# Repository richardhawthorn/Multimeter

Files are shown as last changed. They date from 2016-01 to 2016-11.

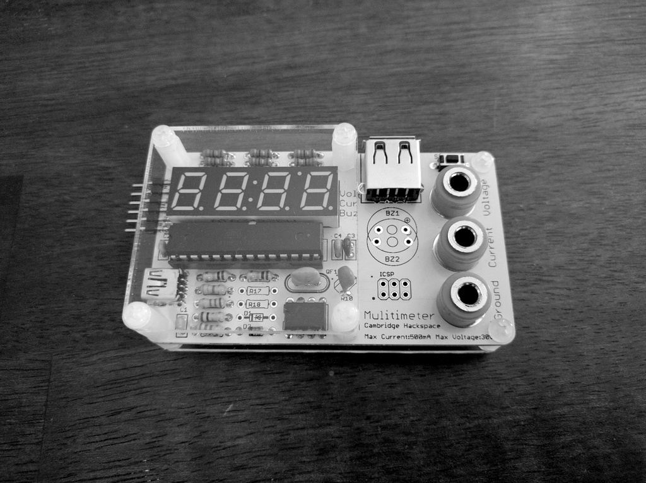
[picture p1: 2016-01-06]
images/image1.jpg

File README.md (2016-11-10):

### Features

- 4 character 7-segment LED display
- ATMEGA328P with Arduino boot-loader
- 5V operation @ 16Mhz
- Voltage and current measurement
- USB-A socket for current passthrough measurement
- 1x button to cycle through modes
- Mini USB power connector
- FTDI programming port
- ICSP port

### License

This work is licensed under a Creative Commons Attribution-ShareAlike 4.0 International License.

<br />
Designed by <a xmlns:cc="http://creativecommons.org/ns#" href="http://www.richardhawthorn.com" property="cc:attributionName" rel="cc:attributionURL" target="_blank">Richard Hawthorn</a><br />
<a rel="license" href="http://creativecommons.org/licenses/by-sa/4.0/" target="_blank">View License</a>

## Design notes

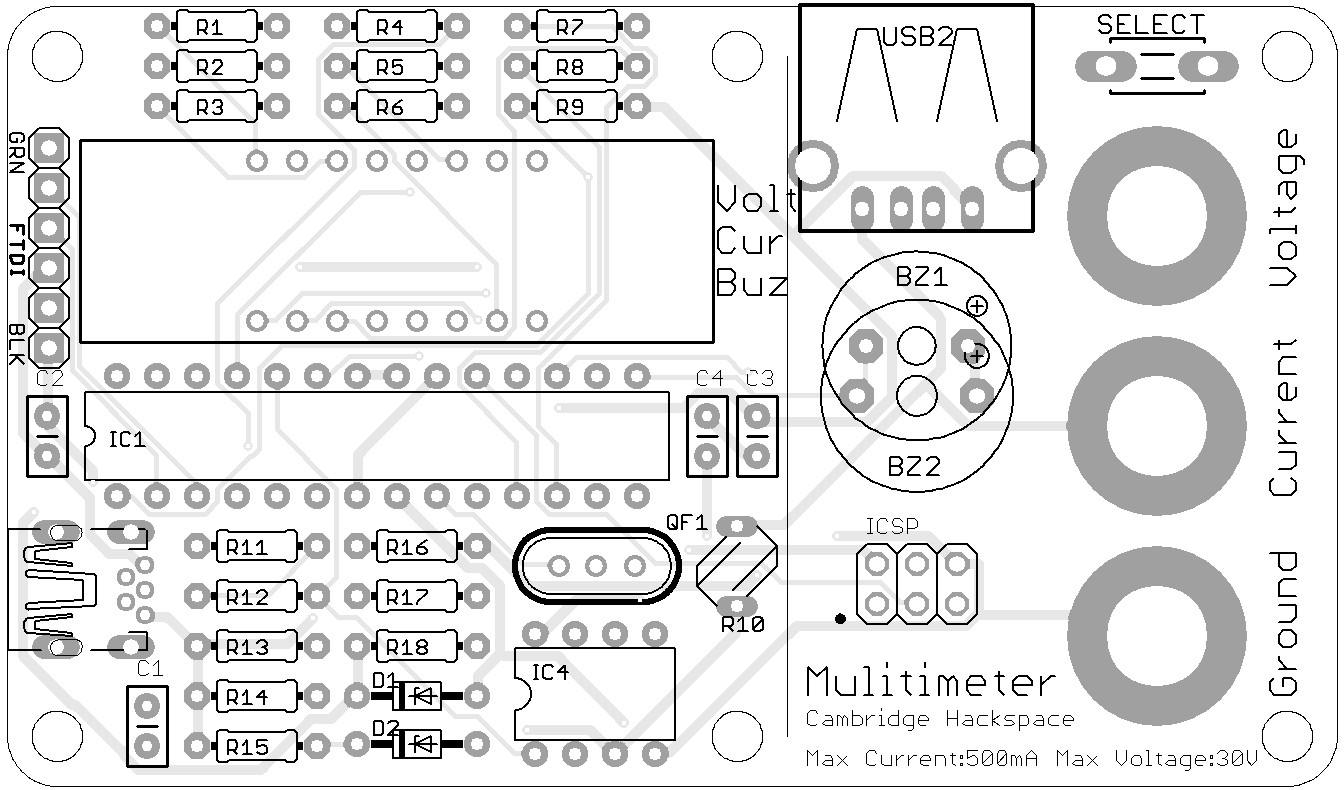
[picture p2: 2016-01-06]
images/pcb_front.png

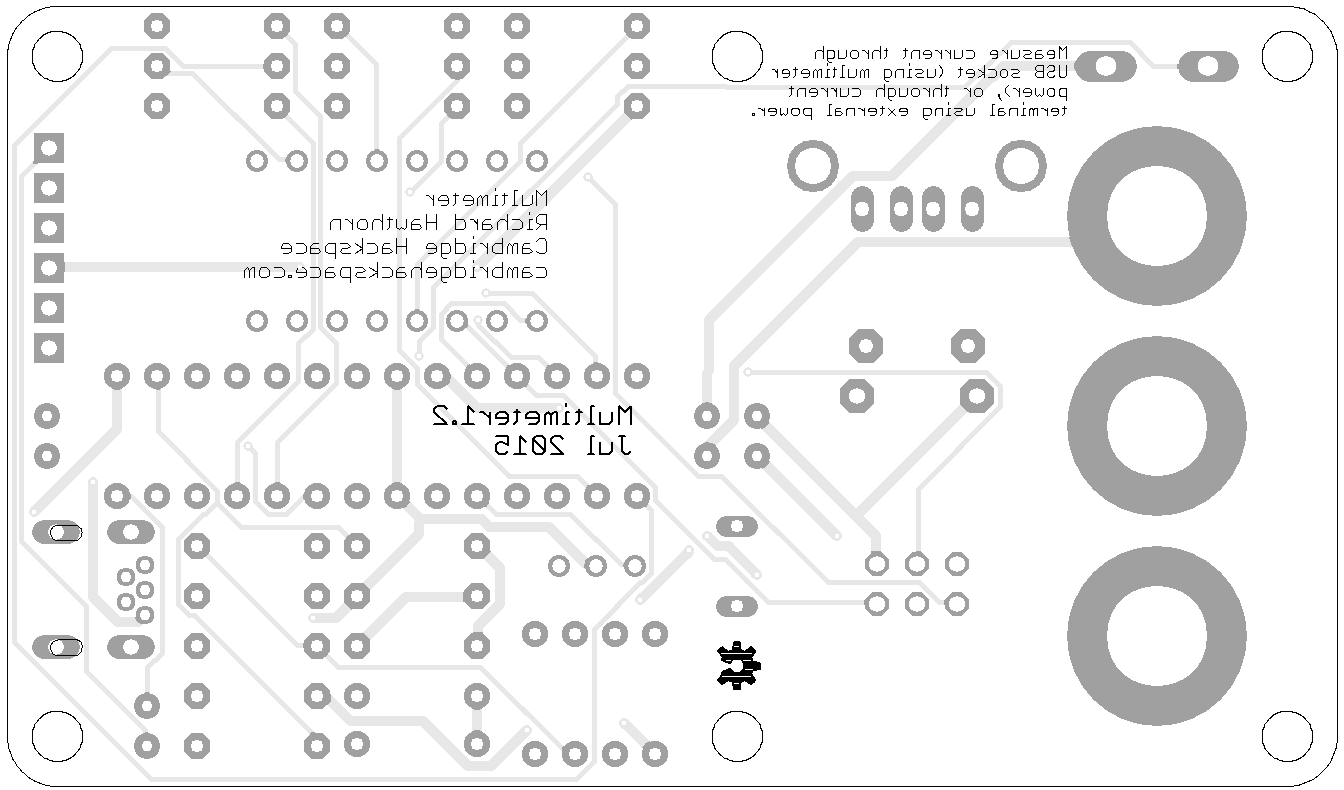
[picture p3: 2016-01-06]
images/pcb_back.png

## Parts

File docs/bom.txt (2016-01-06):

Partlist exported from /Users/richard/Projects/Multimeter/PCB/Multimeter1.2/Multimeter1.2.sch at 7/30/15 9:30 PM

Qty Value       Device                       Package                   Parts                          Description                      
1               PN87520                      PN87520                   USB2                           BERG USB connector               
3   0.1         CAPPTH2                      CAP-PTH-SMALL2            C1, C2, C4                     Capacitor                        
1   10K         R-US_0204/7                  0204/7                    R9                             RESISTOR, American symbol        
3   10k         R-US_0204/7                  0204/7                    R16, R17, R18                  RESISTOR, American symbol        
1   10uf        CAPPTH2                      CAP-PTH-SMALL2            C3                             Capacitor                        
1   12k         R-US_0204/7                  0204/7                    R11                            RESISTOR, American symbol        
2   1k5         R-US_0204/7                  0204/7                    R12, R13                       RESISTOR, American symbol        
1   1r          R-US_0204/7                  0204/7                    R14                            RESISTOR, American symbol        
1   2k          R-US_0204/7                  0204/7                    R15                            RESISTOR, American symbol        
2   5.1V        BZX90                        DO34Z7                    D1, D2                         Z DIODE                          
1   500mA       B57164                       B57164                    R10                            SIEMENS NTC                      
1   7SEG-4DIGIT 7SEG-4DIGIT                  SPARKFUN_7-SEGMENT-4DIGIT LED1                                                            
8   82          R-US_0204/7                  0204/7                    R1, R2, R3, R4, R5, R6, R7, R8 RESISTOR, American symbol        
1   8M10AHC49T  8M10AHC49T                   HC49U                     QF1                            Monolithic Crystal Filters       
1   ATMEGA      ATMEGA168PROUND              DIL28-3-ROUND             IC1                            MICROCONTROLLER                  
3   BANANA      BANANA                       BANANA                    U$1, U$5, U$6                                                   
1   F/QMBIII    F/QMBIII                     F/QMBIII                  BZ1                            BUZZER Source: Buerklin          
1   F/TMB       F/TMB                        F/TMB                     BZ2                            BUZZER Source: Buerklin          
1   FTDI        PINHD-1X6                    1X06                      CN4                            PIN HEADER                       
1   ICSP        PINHD-2X3                    2X03                      ICSP1                          PIN HEADER                       
1   LM358N      LM358N                       DIL08                     IC4                            OP AMP also LM158; LM258; LM2904 
1   SELECT      DTS-3                        DTS-3                     BTN1                                                            
1   USB         MINI-USB_SHIELD5P2-32005-601 32005-601                 X1                             MINI USB-B R/A DIP 5pol.

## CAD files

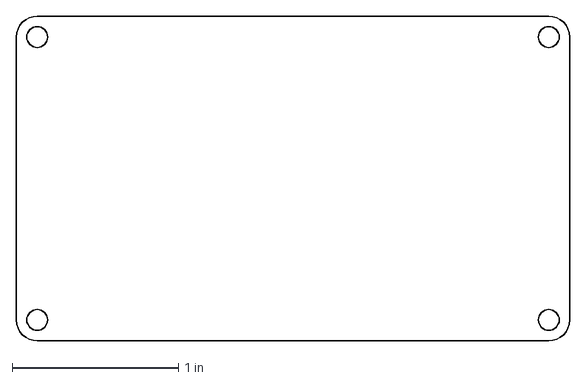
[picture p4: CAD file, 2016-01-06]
enclosure/multimeter.dxf
3.33 x 1.95 in

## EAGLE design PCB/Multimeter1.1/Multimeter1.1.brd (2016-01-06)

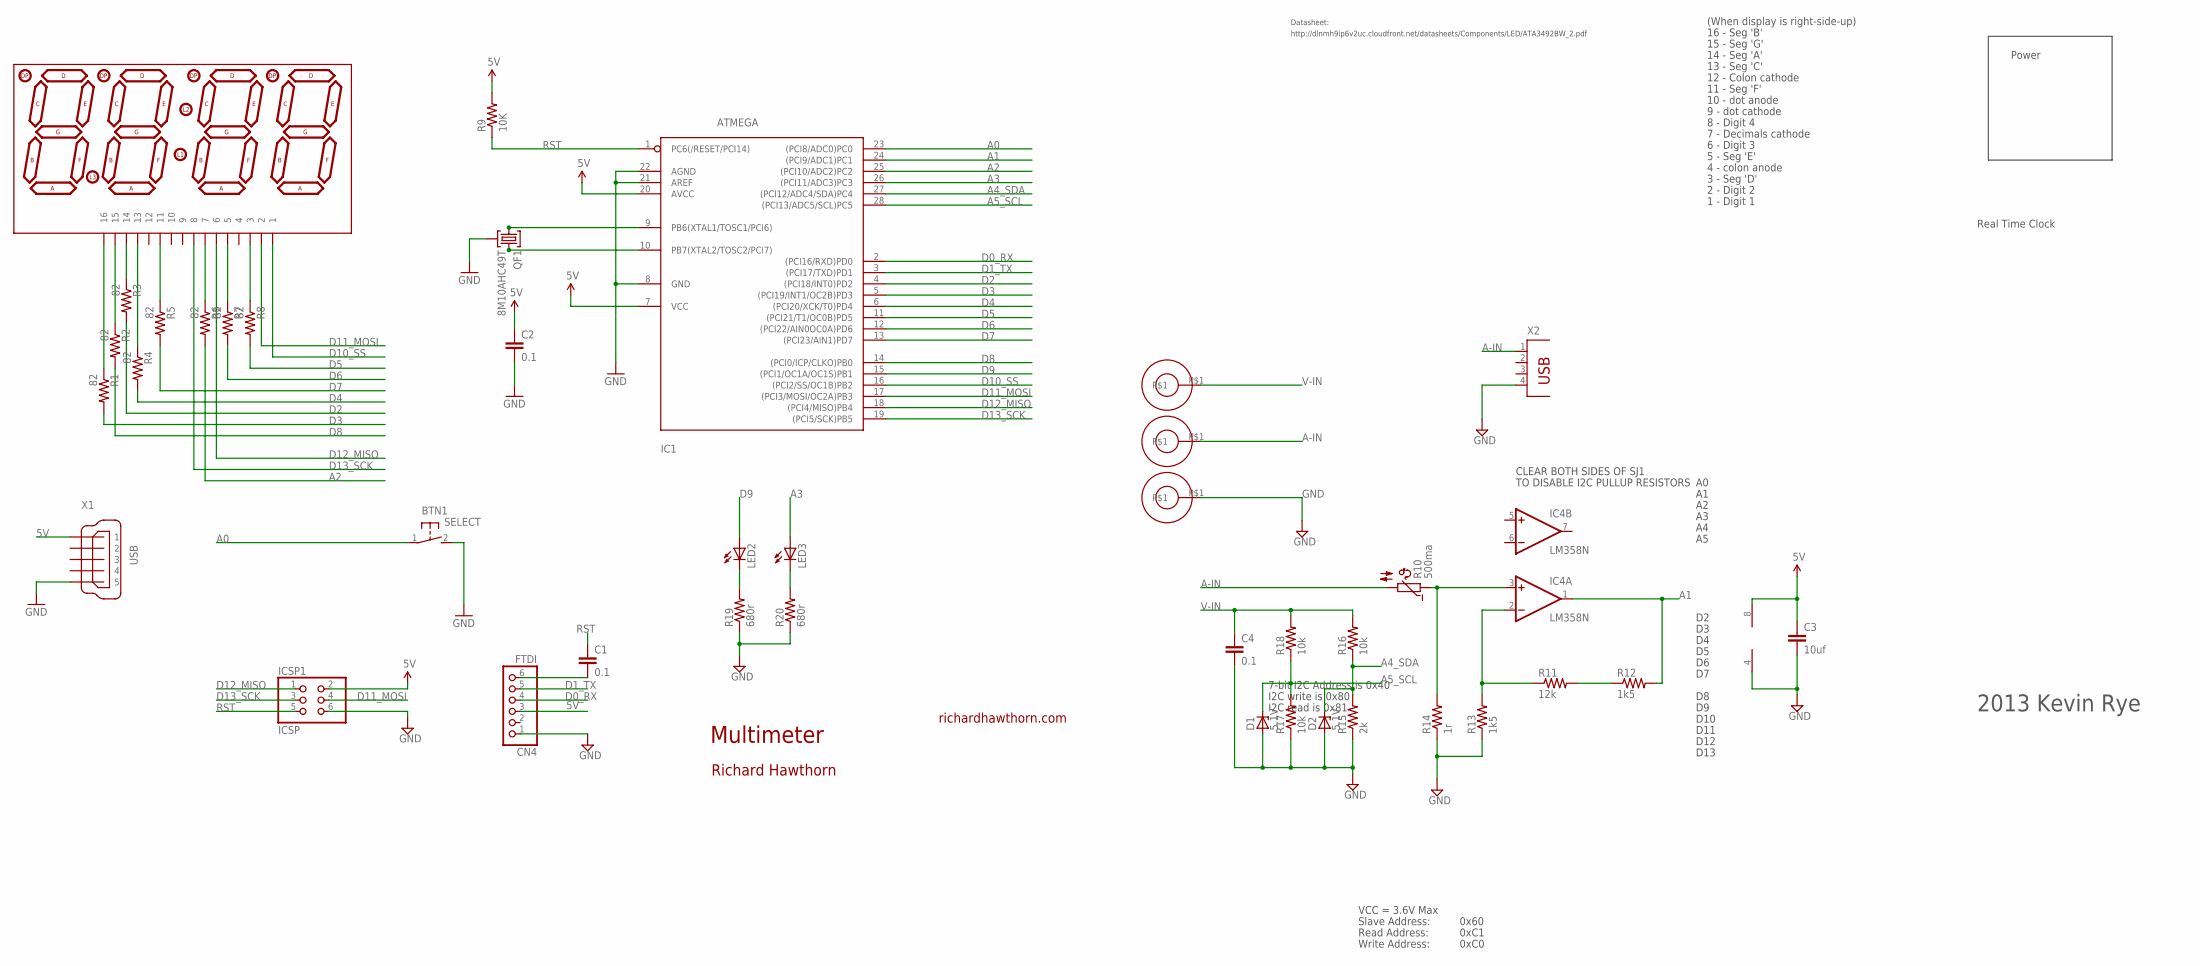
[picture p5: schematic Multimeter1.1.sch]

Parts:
BTN1: SELECT; DTS-3
C1, C2, C4: 0.1; CAP-PTH-SMALL2
C3: 10uf; CAP-PTH-SMALL2
CN4: FTDI; 1X06
D1, D2: 5.1V; DO34Z7
IC1: ATMEGA; DIL28-3-ROUND
IC4: LM358N; DIL08
ICSP1: ICSP; 2X03
LED1: 7SEG-4DIGIT; SPARKFUN_7-SEGMENT-4DIGIT
LED2, LED3: LED5MM
QF1: 8M10AHC49T; HC49U
R1, R2, R3, R4, R5, R6, R7, R8: 82; 0204/7
R9: 10K; 0204/7
R10: 500ma; B57164
R11: 12k; 0204/7
R12, R13: 1k5; 0204/7
R14: 1r; 0204/7
R15: 2k; 0204/7
R16, R17, R18: 10k; 0204/7
R19, R20: 680r; 0204/7
U$1, U$5, U$6: BANANA
X1: USB; 32005-601
X2: PN87520

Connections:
5V: C2.1, C3.1, CN4.3, IC1.7 (VCC), IC1.20 (AVCC), IC4.8 (V+), ICSP1.2, R9.2, X1.1
A0: BTN1.1, IC1.23 ((PCI8/ADC0)PC0)
A1: IC1.24 ((PCI9/ADC1)PC1), IC4.1 (OUT), R12.2
A2: IC1.25 ((PCI10/ADC2)PC2), R6.2
A3: IC1.26 ((PCI11/ADC3)PC3), LED3.A
A4_SDA: D2.C, IC1.27 ((PCI12/ADC4/SDA)PC4), R15.2, R16.1
A5_SCL: D1.C, IC1.28 ((PCI13/ADC5/SCL)PC5), R17.2, R18.1
A-IN: R10.2, U$5.P$1, X2.1
D0_RX: CN4.4, IC1.2 ((PCI16/RXD)PD0)
D1_TX: CN4.5, IC1.3 ((PCI17/TXD)PD1)
D2: IC1.4 ((PCI18/INT0)PD2), R3.2
D3: IC1.5 ((PCI19/INT1/OC2B)PD3), R1.2
D4: IC1.6 ((PCI20/XCK/T0)PD4), R4.2
D5: IC1.11 ((PCI21/T1/OC0B)PD5), R8.2
D6: IC1.12 ((PCI22/AIN0OC0A)PD6), R7.2
D7: IC1.13 ((PCI23/AIN1)PD7), R5.2
D8: IC1.14 ((PCI0/ICP/CLKO)PB0), R2.2
D9: IC1.15 ((PCI1/OC1A/OC1S)PB1), LED2.A
D10_SS: IC1.16 ((PCI2/SS/OC1B)PB2), LED1.1
D11_MOSI: IC1.17 ((PCI3/MOSI/OC2A)PB3), ICSP1.4, LED1.2
D12_MISO: IC1.18 ((PCI4/MISO)PB4), ICSP1.1, LED1.6
D13_SCK: IC1.19 ((PCI5/SCK)PB5), ICSP1.3, LED1.8
GND: BTN1.2, C2.2, C3.2, C4.2, CN4.1, D1.A, D2.A, IC1.8 (GND), IC1.21 (AREF), IC1.22 (AGND), IC4.4 (V-), ICSP1.6, QF1.2, R13.1, R14.1, R15.1, R17.1, R19.1, R20.1, U$6.P$1, X1.5, X2.4
unnamed: LED1.16, R1.1
unnamed: IC4.2 (-IN), R11.1, R13.2
unnamed: LED1.15, R2.1
unnamed: LED2.K (C), R19.2
unnamed: LED3.K (C), R20.2
unnamed: R11.2, R12.1
unnamed: LED1.7, R6.1
unnamed: IC4.3 (+IN), R10.1, R14.2
unnamed: IC1.9 (PB6(XTAL1/TOSC1/PCI6)), QF1.1
unnamed: C1.2, CN4.6
unnamed: LED1.13, R4.1
unnamed: LED1.14, R3.1
unnamed: LED1.11, R5.1
unnamed: IC1.10 (PB7(XTAL2/TOSC2/PCI7)), QF1.3
unnamed: LED1.5, R7.1
unnamed: LED1.3, R8.1
RST: C1.1, IC1.1 (PC6(/RESET/PCI14)), ICSP1.5, R9.1
V-IN: C4.1, R16.2, R18.2, U$1.P$1

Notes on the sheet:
Multimeter
richardhawthorn.com
Richard Hawthorn
CLEAR BOTH SIDES OF SJ1
TO DISABLE I2C PULLUP RESISTORS
7-bit I2C Address is 0x40
I2C write is 0x80
I2C read is 0x81
VCC = 3.6V Max
Read Address:
Write Address:
Slave Address:
0x60
0xC1
0xC0
14 - Seg 'A'
13 - Seg 'C'
12 - Colon cathode
11 - Seg 'F'
10 - dot anode
9 - dot cathode
8 - Digit 4
7 - Decimals cathode
6 - Digit 3
5 - Seg 'E'
4 - colon anode
3 - Seg 'D'
2 - Digit 2
Real Time Clock
1 - Digit 1
15 - Seg 'G'
16 - Seg 'B'
D10
D11
D12
D13
http://dlnmh9ip6v2uc.cloudfront.net/datasheets/Components/LED/ATA3492BW_2.pdf
Datasheet:
Power
(When display is right-side-up)

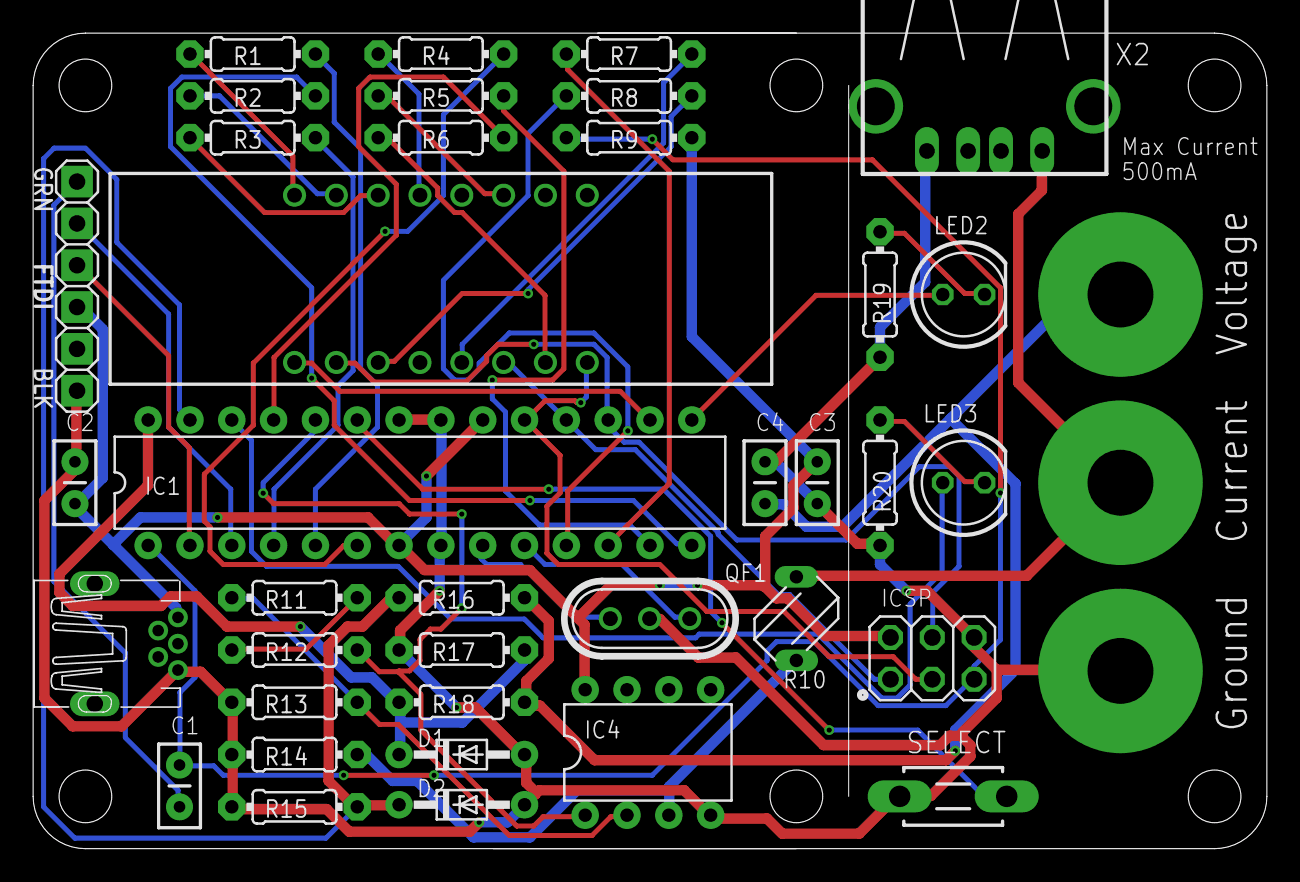
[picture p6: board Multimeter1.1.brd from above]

Board: 2 copper layers, 74.9 x 49.5 mm, 41 parts (1 on the bottom side), 41 nets.

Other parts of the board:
U$3: OSHW-LOGO-S

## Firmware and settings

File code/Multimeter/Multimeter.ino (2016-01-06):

//   Multimeter1.1
//   Richard Hawthorn
//   Cambridge Hackspace
//   Based on code from Kevin Rye
//   2015-08-08
//
//   7 segment led pixels
//
//    _____         __A__
//   |     |       F     B
//   |_____|  -->  |--G--|
//   |     |       E     C
//   |_____|       |__D__|
//
//   Characters
//    _____     _____     _____     _____ 
//   |     |   |     | . |     | o |     |
//   |_____|   |_____|   |_____|   |_____|
//   |     |   |     | . |     |   |     |
//   |_____| o |_____| o |_____| o |_____| o
//      1         2         3         4
//


//define Pins
int segmentD = 5;
int segmentE = 6;
int segmentF = 7;
int segmentA = 2;
int segmentB = 3;
int segmentC = 4;
int segmentG = 8;
int digitOne = 10;
int digitTwo = 11;
int digitThree = 12;
int digitFour = 13;
int selectButton = A0;
int decimal = A2;

int voltagePin = A4;
int currentPin = A1;

float voltage;
float current;
float value;

char mode = 'v';

int displayPause = 2;

const int meterDelay = 500;

unsigned long startMillis = millis();

//setup
void setup() {

  //pin modes
  pinMode(segmentA, OUTPUT);
  pinMode(segmentB, OUTPUT);
  pinMode(segmentC, OUTPUT);
  pinMode(segmentD, OUTPUT);
  pinMode(segmentE, OUTPUT);
  pinMode(segmentF, OUTPUT);
  pinMode(segmentG, OUTPUT);
  pinMode(decimal, OUTPUT);
  pinMode(digitOne, OUTPUT);
  pinMode(digitTwo, OUTPUT);
  pinMode(digitThree, OUTPUT);
  pinMode(digitFour, OUTPUT);
  
  //buttons (with pullups)
  pinMode(selectButton, INPUT_PULLUP);
  
  //setup serial line for debugging
  Serial.begin(9600);
  
}





void checkVoltage(){
  
  voltage = analogRead(voltagePin);
  voltage = (voltage / 1024) * 29.00 * 100.00;
  value = voltage;
  
}

void checkCurrent(){
  
  current = analogRead(currentPin);
  current = (((current/1024.00) * 5.00) / 9.866) * 1000;
  value = current;
  
}



void checkButtons(){
  
   //select button pressed
  if (digitalRead(selectButton) == LOW) {
    //basic debounce
    delay(200);
    
    resetNumbers();
    digitalWrite(digitFour,HIGH);
    
    if (mode == 'v'){
      mode = 'c';
      digitalWrite(segmentG,LOW);  
    } else {
      mode = 'v';
      digitalWrite(segmentA,LOW);
    }
    
    delay(1000);
    resetNumbers();
    
  } 
}

//display the time
void showNum(int n) {

  //display digit X
  //digit 1 - only display if time is greater thatn 9:59
  int n1 = (n%10000)/1000;
  if (n > 999) {
    printNumber(n1,1);
  }
  delay(displayPause);
  resetNumbers();

  //digit 2
  int n2 = (n%1000)/100;
  printNumber(n2,2); 
  delay(displayPause);
  resetNumbers();

  //digit 3
  int n3 = (n%100)/10;
  printNumber(n3,3);
  delay(displayPause);
  resetNumbers();

  //digit 4
  int n4 = n%10;
  printNumber(n4,4); 
  delay(displayPause);
  resetNumbers();

}

//reset the screen, so everything is off
void resetNumbers(){
  
    digitalWrite(digitOne,LOW);
    digitalWrite(digitTwo,LOW);
    digitalWrite(digitThree,LOW);
    digitalWrite(digitFour,LOW);
    digitalWrite(decimal,HIGH);
    digitalWrite(segmentA,HIGH);
    digitalWrite(segmentB,HIGH);
    digitalWrite(segmentC,HIGH);
    digitalWrite(segmentD,HIGH);
    digitalWrite(segmentE,HIGH);
    digitalWrite(segmentF,HIGH);
    digitalWrite(segmentG,HIGH);  
  
}

//output a specific number in a specific position
//n = number, d = position
void printNumber(int n, int d) {
 
  if ((n > 9) || (n < 0)){
    return;  
  }
  
  if ((d > 4) || (d < 1)){
    return;  
  }
  
  //d is the display to illuminate
  if(d==1)  {
    digitalWrite(digitOne,HIGH);
    digitalWrite(digitTwo,LOW);
    digitalWrite(digitThree,LOW);
    digitalWrite(digitFour,LOW);
    if (mode == 'c'){
      digitalWrite(decimal,LOW); //decimal on
    }
  } 

  if(d==2) {
    digitalWrite(digitOne,LOW);
    digitalWrite(digitTwo,HIGH);
    digitalWrite(digitThree, LOW);
    digitalWrite(digitFour,LOW);
    if (mode == 'v'){
      digitalWrite(decimal,LOW); //decimal on
    }
  }

  if(d==3) {
    digitalWrite(digitOne,LOW);
    digitalWrite(digitTwo,LOW);
    digitalWrite(digitThree,HIGH);
    digitalWrite(digitFour,LOW);
    //digitalWrite(decimal,HIGH); //decimal off
  }

  if(d==4) {
    digitalWrite(digitOne,LOW);
    digitalWrite(digitTwo,LOW);
    digitalWrite(digitThree,LOW);
    digitalWrite(digitFour,HIGH);
    //digitalWrite(decimal,HIGH); //decimal off
  }
 
  //n is for the number to be displayed
  switch(n) {
  case 0:
    digitalWrite(segmentA,LOW);
    digitalWrite(segmentB,LOW);
    digitalWrite(segmentC,LOW);
    digitalWrite(segmentD,LOW);
    digitalWrite(segmentE,LOW);
    digitalWrite(segmentF,LOW);
    digitalWrite(segmentG,HIGH);
    break;
    

  case 1:
    digitalWrite(segmentA,HIGH);
    digitalWrite(segmentB,LOW);
    digitalWrite(segmentC,LOW);
    digitalWrite(segmentD,HIGH);
    digitalWrite(segmentE,HIGH);
    digitalWrite(segmentF,HIGH);
    digitalWrite(segmentG,HIGH);
    break;

  case 2:
    digitalWrite(segmentA,LOW);
    digitalWrite(segmentB,LOW);
    digitalWrite(segmentC,HIGH);
    digitalWrite(segmentD,LOW);
    digitalWrite(segmentE,LOW);
    digitalWrite(segmentF,HIGH);
    digitalWrite(segmentG,LOW);
    break;

  case 3:
    digitalWrite(segmentA,LOW);
    digitalWrite(segmentB,LOW);
    digitalWrite(segmentC,LOW);
    digitalWrite(segmentD,LOW);
    digitalWrite(segmentE,HIGH);
    digitalWrite(segmentF,HIGH);
    digitalWrite(segmentG,LOW);
    break;

  case 4:
    digitalWrite(segmentA,HIGH);
    digitalWrite(segmentB,LOW);
    digitalWrite(segmentC,LOW);
    digitalWrite(segmentD,HIGH);
    digitalWrite(segmentE,HIGH);
    digitalWrite(segmentF,LOW);
    digitalWrite(segmentG,LOW);
    break;

  case 5:
    digitalWrite(segmentA,LOW);
    digitalWrite(segmentB,HIGH);
    digitalWrite(segmentC,LOW);
    digitalWrite(segmentD,LOW);
    digitalWrite(segmentE,HIGH);
    digitalWrite(segmentF,LOW);
    digitalWrite(segmentG,LOW);
    break;

  case 6:
    digitalWrite(segmentA,LOW);
    digitalWrite(segmentB,HIGH);
    digitalWrite(segmentC,LOW);
    digitalWrite(segmentD,LOW);
    digitalWrite(segmentE,LOW);
    digitalWrite(segmentF,LOW);
    digitalWrite(segmentG,LOW);
    break;

  case 7:
    digitalWrite(segmentA,LOW);
    digitalWrite(segmentB,LOW);
    digitalWrite(segmentC,LOW);
    digitalWrite(segmentD,HIGH);
    digitalWrite(segmentE,HIGH);
    digitalWrite(segmentF,HIGH);
    digitalWrite(segmentG,HIGH);
    break;

  case 8:
    digitalWrite(segmentA,LOW);
    digitalWrite(segmentB,LOW);
    digitalWrite(segmentC,LOW);
    digitalWrite(segmentD,LOW);
    digitalWrite(segmentE,LOW);
    digitalWrite(segmentF,LOW);
    digitalWrite(segmentG,LOW);
    break;

  case 9:
    digitalWrite(segmentA,LOW);
    digitalWrite(segmentB,LOW);
    digitalWrite(segmentC,LOW);
    digitalWrite(segmentD,LOW);
    digitalWrite(segmentE,HIGH);
    digitalWrite(segmentF,LOW);
    digitalWrite(segmentG,LOW);
    break;
  }
}





//main loop
void loop() {
 
  
  if (millis() - startMillis > meterDelay){
    if (mode == 'v'){
      checkVoltage();
    } else {
      checkCurrent();
    }
    
    startMillis = millis();
  }
  
  showNum(value);
  checkButtons();
  
}

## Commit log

2016-01-06 Adding v1 and v2 pcb designs
    [Multimeter1.1.brd, Multimeter1.1.sch, Multimeter1.2.brd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]
2016-01-06 adding pcb images
2016-01-06 adding base drawings
    [multimeter.dxf]
2016-01-06 first version of the Arduino code

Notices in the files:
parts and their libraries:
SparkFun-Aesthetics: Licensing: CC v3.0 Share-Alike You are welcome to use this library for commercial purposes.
